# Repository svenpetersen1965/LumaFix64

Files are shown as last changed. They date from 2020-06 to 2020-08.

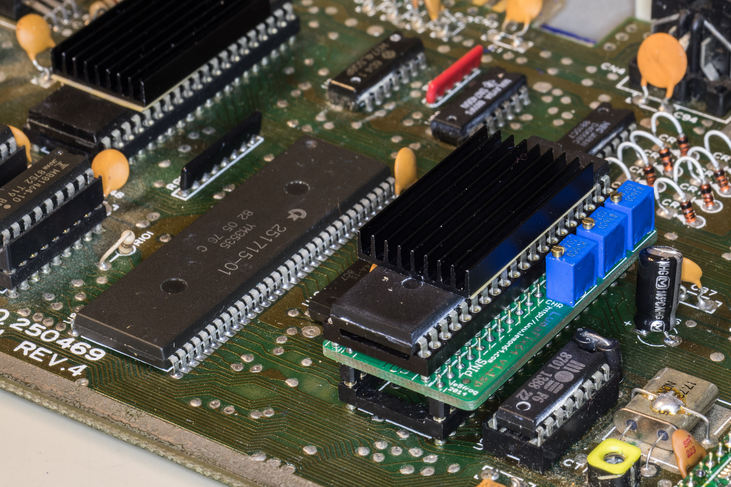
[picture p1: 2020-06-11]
v1.2/Bilder/416_LumaFix64_on_ASSY250469.JPG

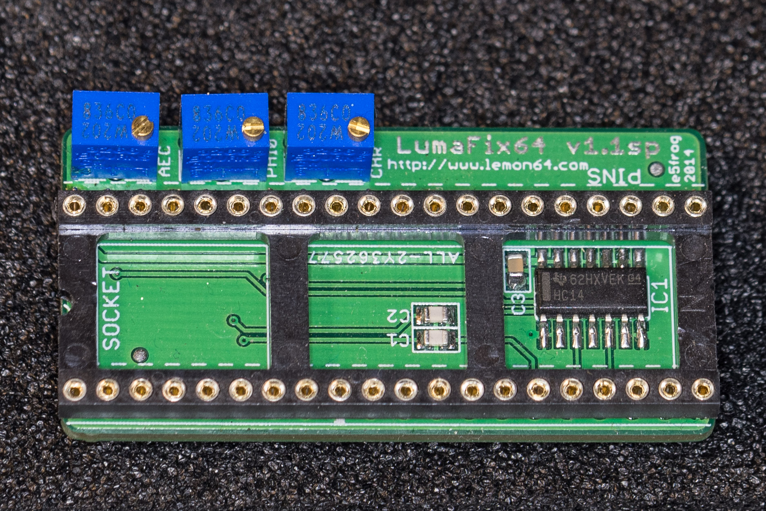
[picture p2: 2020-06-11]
v1.2/Bilder/0407_LumaFix64.JPG

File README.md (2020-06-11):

# LumaFix64
The LumaFix64 is not my design. It is based on <a href="https://www.lemon64.com/forum/viewtopic.php?t=40570&start=375">e5frog's LumaFix64 design</a>, which was released in March 7th, 2018 in the Lemon64.com forum. The changes in my design are:
* No through hole parts
* PCB a little bit narrower
* the Chroma potentiometer (CHR) can be replaced with a fix resistor or just a solder bridge

The Chroma potentiometer is IMHO not required, because it is not desirable to reduce the chominance level before the composite video signal is generated in the RF modulator. 

The LumaFix64 requires the precision round pin strips, because those are narrow enough not to break the socket of VIC-II chip. Since these pin strips are fragile, the LumaFix64 has to be handle with care.

I have received the permission of e5frog for publishing these files in this github repository (see screen shot in the "pictures" folder).

# BOM value
The calculation of the BOM values is available in the EXCEL folder. The total BOM value is 9,63€ (May 2020). This includes the Chroma pot and domestic pin strips. It is possible to save money on both, when ordering overseas.

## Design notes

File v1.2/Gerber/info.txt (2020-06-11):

      
   
       Board: LumaFix64 v1.1sp (e5frog & http://www.lemon64.com)
       Rev.:  1.2
  
       Files:
       ======
  
       All Gerber files are generated in extended gerber format (RS274X)
       *.TOP        : Film top copper
       *.BOT        :  -"- bottom copper
       *.STC        :  -"- top soldermask 
       *.STS        :  -"- bottom soldermask
       *.CRC        :  -"- cream top
       *.PLC        :  -"- silk screen top
       *.PLS        :  -"- silk screen bottom
       *.DK         : Drills plated Through (Excellon)
       *.NDK        : Drills not plated Through (Excellon)
       *.OUT        : Board outline

       Board Size:
       ===========
       Length     :   50.75 mm
       Width      :   25.94 mm
       Thickness  :   1.6 mm
       Material   :   FR 4
       Copper     :   35 um
       Surface    :   HASL
       
       Remarks:
       ========
       Drills not plated Through do not exsist on this board.
       drills >= 0.35mm
       width >= 8mil
       distance >= 6mil

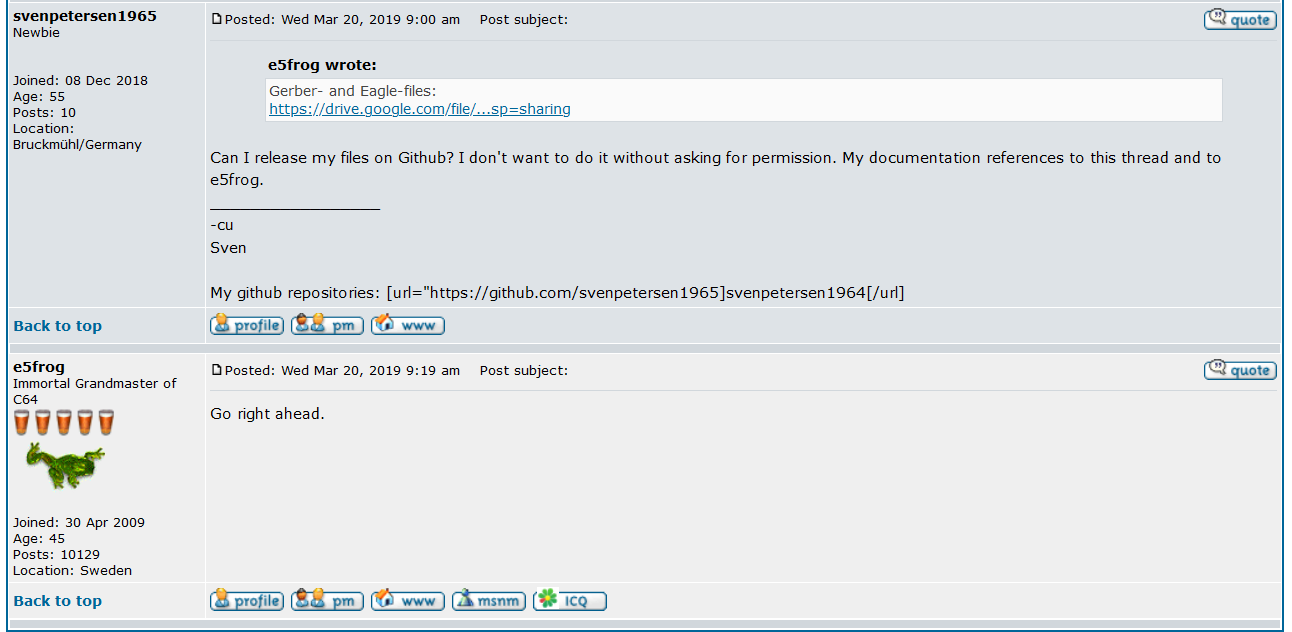
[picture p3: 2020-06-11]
v1.2/Bilder/e5frog_permission_20190320.png

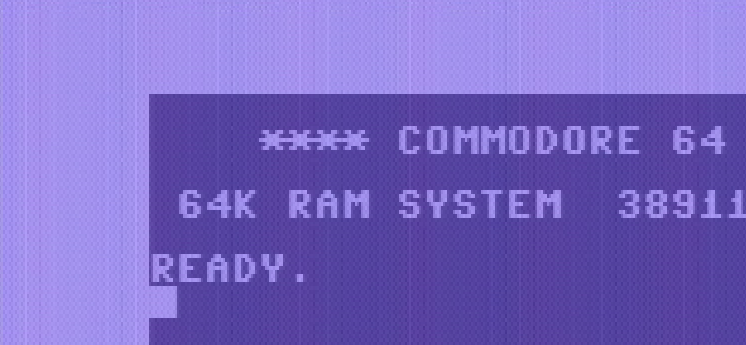
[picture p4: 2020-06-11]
v1.2/Bilder/C64_Bild_ohne_Lumafix.png

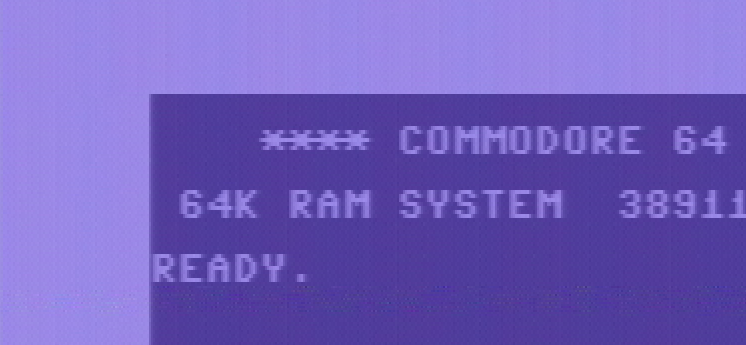
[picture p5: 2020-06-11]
v1.2/Bilder/C64_Bild_mit_Lumafix.png

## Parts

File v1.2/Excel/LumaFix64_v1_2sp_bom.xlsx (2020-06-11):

LumaFix64 Rev. 1.2sp
Partlist Rev. 1.20
Pos. | Each | Value | Footprint | Names | Anmerkung
1 | 1 | 110-2-01-01.2sp | 2 Layers | PCB Rev. 1.2sp | 2 Layers, Cu 35µ, HASL, 50.75mm 25.94mm, 1.6mm FR4
2 | 1 | DIP-40 | GS40P | SOCKET | Dual In Line Socket, Reichelt: GS40P
3 | 1 | 10120540 | BKL_10120540_2X20 | PINS | Precision pin header, bkl-electronic.de Art.-Nr. 10120540, Reichelt BKL 10120540
4 | 1 | 100n | 0805 | C3 | SMD capacitor
5 | 1 | 2k | POT_B64W | CHR | optional, only if chroma adjustment is desired. Bournes 3266W-1-202, Reichelt: BOU 3266W-1-202
6 | 2 | 2k | POT_B64W | AEC, PHI0 | Bournes 3266W-1-202, Reichelt: BOU 3266W-1-202
7 | 2 | 47p | 0805 | C1, C2 | SMD capacitor
8 | 1 | 74HCT14D | SO14 | IC1 | Hex schmitt trigger inverter, e.g. NXP, Reichelt 74HCT 14D NXP
9 | 1 | n/a | 0805 | R1 | not assembled

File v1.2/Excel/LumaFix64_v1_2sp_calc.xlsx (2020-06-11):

LumaFix64 Rev. 1.2sp
Kalkulation
Pos. | Each | Value | Footprint | €/each | Sum
1 | 1 | 110-2-01-01.2sp | 2 Layers | 1.00 € | 1.00 €
2 | 1 | DIP-40 | GS40P | 0.62 € | 0.62 €
3 | 1 | 10120540 | BKL_10120540_2X20 | 1.99 € | 1.99 €
4 | 1 | 100n | 0805 | 0.05 € | 0.05 €
5 | 1 | 2k | POT_B64W | 1.85 € | 1.85 €
6 | 2 | 2k | POT_B64W | 1.85 € | 3.70 €
7 | 2 | 47p | 0805 | 0.10 € | 0.20 €
8 | 1 | 74HCT14D | SO14 | 0.22 € | 0.22 €
9 | 1 | n/a | 0805 | 0.00 € | 0.00 €
10 |  |  |  | Total | 9.63 €

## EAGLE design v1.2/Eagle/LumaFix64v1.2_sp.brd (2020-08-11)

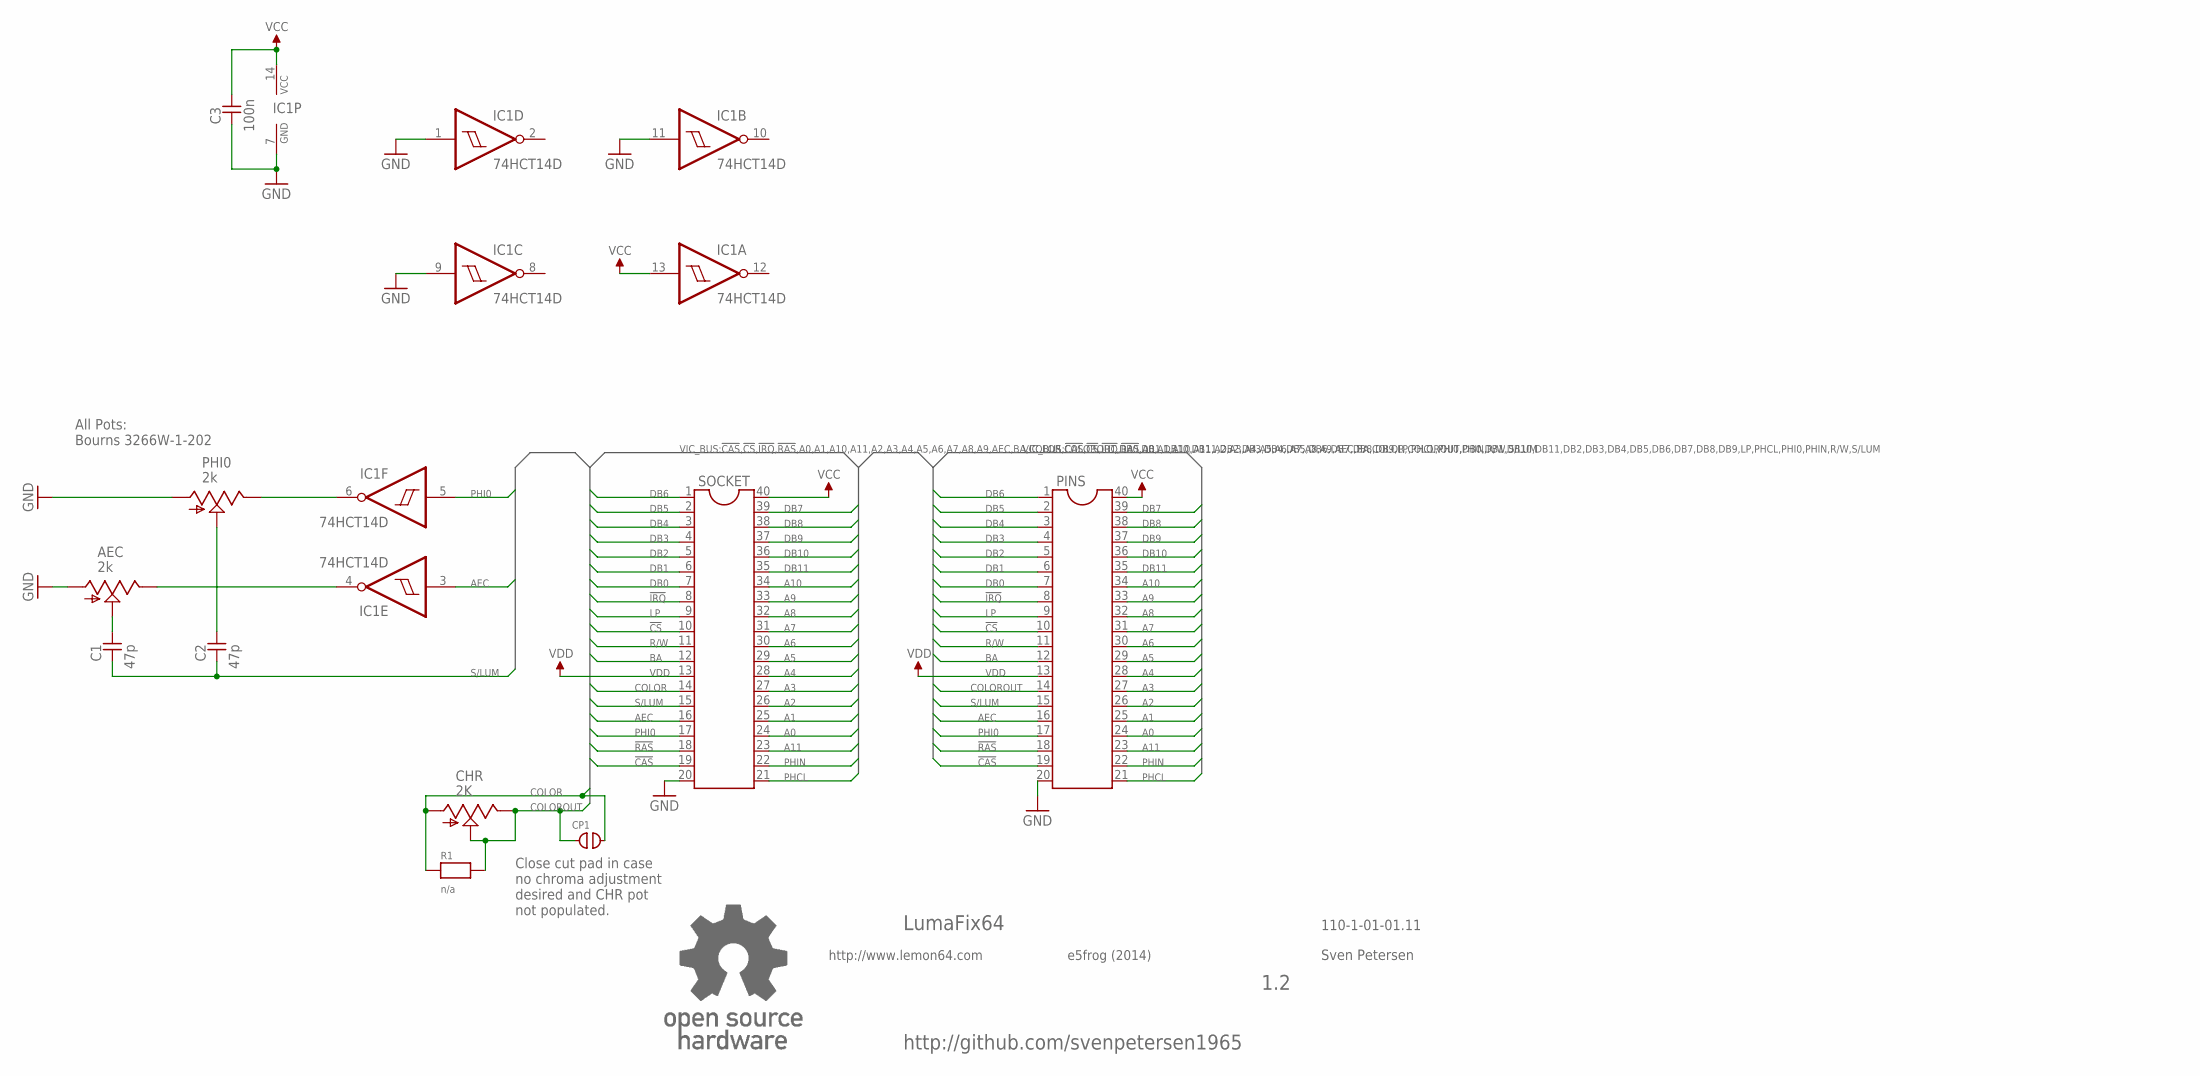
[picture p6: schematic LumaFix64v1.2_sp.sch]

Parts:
AEC: 2k; POT_B64W
C1, C2: 47p; 0805
C3: 100n; 0805
CHR: 2K; POT_B64W
CP1: OPEN; CP_OP
IC1: 74HCT14D; SO14
PHI0: 2k; POT_B64W
PINS: IC-PACKAGE_DIL40_10120540; BLK_10120540_2X20
R1: n/a; 0805
SOCKET: IC-PACKAGE_DIL40GS40P; GS40P
U$13: OPEN_SOURCE_HW; OPENHW

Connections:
!CAS: PINS.19, SOCKET.19
!CS: PINS.10, SOCKET.10
!IRQ: PINS.8, SOCKET.8
!RAS: PINS.18, SOCKET.18
A0: PINS.24, SOCKET.24
A1: PINS.25, SOCKET.25
A2: PINS.26, SOCKET.26
A3: PINS.27, SOCKET.27
A4: PINS.28, SOCKET.28
A5: PINS.29, SOCKET.29
A6: PINS.30, SOCKET.30
A7: PINS.31, SOCKET.31
A8: PINS.32, SOCKET.32
A9: PINS.33, SOCKET.33
A10: PINS.34, SOCKET.34
A11: PINS.23, SOCKET.23
AEC: IC1.3 (I), PINS.16, SOCKET.16
BA: PINS.12, SOCKET.12
COLOR: CHR.A, CP1.2, R1.1, SOCKET.14
COLOROUT: CHR.E, CHR.S, CP1.1, PINS.14, R1.2
DB0: PINS.7, SOCKET.7
DB1: PINS.6, SOCKET.6
DB2: PINS.5, SOCKET.5
DB3: PINS.4, SOCKET.4
DB4: PINS.3, SOCKET.3
DB5: PINS.2, SOCKET.2
DB6: PINS.1, SOCKET.1
DB7: PINS.39, SOCKET.39
DB8: PINS.38, SOCKET.38
DB9: PINS.37, SOCKET.37
DB10: PINS.36, SOCKET.36
DB11: PINS.35, SOCKET.35
GND: AEC.A, C3.1, IC1.1 (I), IC1.7 (GND), IC1.9 (I), IC1.11 (I), PHI0.A, PINS.20, SOCKET.20
LP: PINS.9, SOCKET.9
unnamed: AEC.S, C1.2
unnamed: C2.2, PHI0.S
unnamed: AEC.E, IC1.4 (O)
unnamed: IC1.6 (O), PHI0.E
PHCL: PINS.21, SOCKET.21
PHI0: IC1.5 (I), PINS.17, SOCKET.17
PHIN: PINS.22, SOCKET.22
R/W: PINS.11, SOCKET.11
S/LUM: C1.1, C2.1, PINS.15, SOCKET.15
VCC: C3.2, IC1.13 (I), IC1.14 (VCC), PINS.40, SOCKET.40
VDD: PINS.13, SOCKET.13

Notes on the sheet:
LumaFix64
http://www.lemon64.com
e5frog (2014)
1.2
110-1-01-01.11
Sven Petersen
All Pots: Bourns 3266W-1-202
Close cut pad in case no chroma adjustment desired and CHR pot not populated.
http://github.com/svenpetersen1965

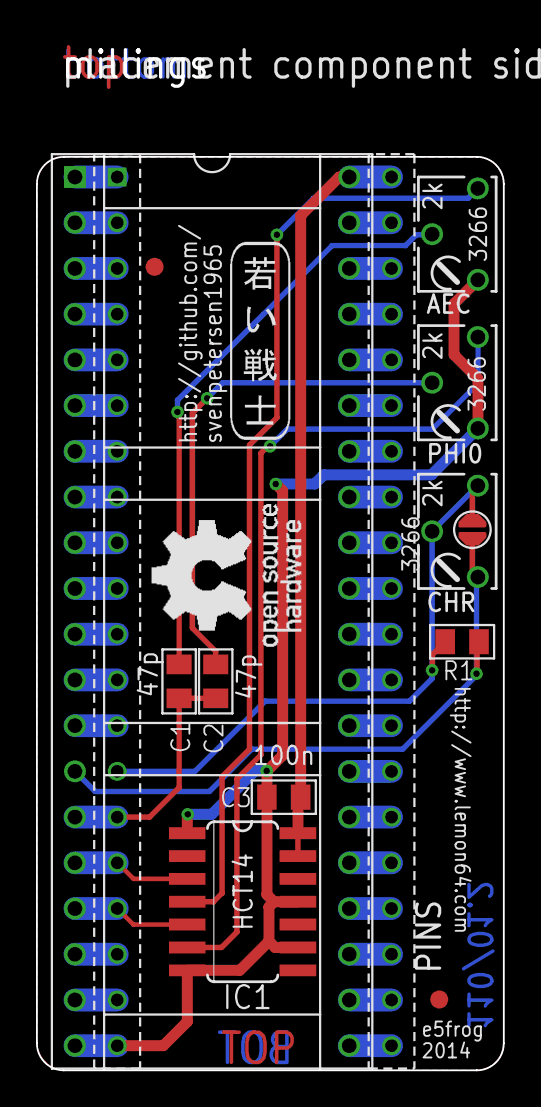
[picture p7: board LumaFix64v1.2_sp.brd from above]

Board: 2 copper layers, 25.9 x 50.8 mm, 17 parts (0 on the bottom side), 45 nets.

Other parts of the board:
U$7: 2LAYER
U$9: PCB-TITLE/
U$10, U$11: SMD_REF_R1MM
U$12: SVEN_TAG

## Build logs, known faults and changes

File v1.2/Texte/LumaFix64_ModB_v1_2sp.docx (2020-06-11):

LumaFix64 Rev. 1.2sp

Module Description

# 1. Preface

It is a known fact, that some digitals signals are interfering with the video output signals inside the VIC-II chip of the Commodore C64. This results in a typical vertical strip pattern in the monitor output of the C64. The main culprits are AEC and PHI0 (VIC-II pin 16 and 17).

This topic was discussed in the lemon64.com forum in December 2011 (https://www.lemon64.com/forum/viewtopic.php?t=40570&start=0), where the attempt to cancel out these interferences was mentioned, that was released by the user ikary_01 in forum64.de in October 2010, called „C64-Streifenfix“ (https://www.forum64.de/index.php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 (https://www.forum64.de/index.php?s=b329abcb4ddda3e4efab6bcffade57ad2a5b7f33) & https://sd2snes.de/~ikari/pics/ ).

This design is based on the eagle files LumaFix64v1.0_B64W, that e5frog released in the lemon64.com forum March 7th, 2018. (https://www.lemon64.com/forum/viewtopic.php?t=40570&start=375)

# 2. Functionality

The signals AEC and PHI0 are inverted, then attenuated by potentiometers (AEC & PHI0) and coupled into the S/LUM signal (VIC-II pin 15) via a small (47p) capacity). The potentiometers can be adjusted to minimize the interferences of the signals mentioned above.

Further on, the chrominance signal of the VIC-II chip has an amplitude, which is too high for most modern TVs, which results in a poor color quality. Many C64 video cables solve this issue by inserting a 330Ω resistor into the chrominance output signal. The LumaFix64 solves this issue with a pot (CHR) inserted in the signal. This pot can stay not populated and the cut pad CP1 can be closed instead.

# 3. Revision History

## v1.0 B64W → v1.1sp

- The issue of the original eagle files with Eagle 9 was fixed
- The schematic was restructured
- The THT ICs and capacitors were left out
- The footprints of the socket, pin headers and pots were changed
- The inverter IC 74HCT14 has a 100n buffer cap
- The cut-pad CP1for bridging the CHR pot was added, a 330Ω resistor (0603) can be placed on this cut-pad for having a fix resistor in the chrominance output.
- The width of the board was reduced to 25.94mm
- The layout is new

## v1.1sp → v1.2sp

- PCB Revision
- R1 is new to replace the CHR pot if not required

LumaFix64_ModB_v1_2sp.docx 03.04.2020 14:15 Erstellt von Sven Petersen Seite 2 von 2 Dok.-Nr.: 000-8-00-00

LumaFix64_ModB_v1_2sp.docx 03.04.2020 14:15 Drafted by Sven Petersen Page 1 of 1 Doc.-No.: 110-6-01-01.2sp

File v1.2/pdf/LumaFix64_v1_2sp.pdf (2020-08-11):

LumaFix64_ModB_v1_2sp.docx | | 03.04.2020 14:15
Drafted by Sven Petersen | Page 1 of 1 | Doc.-No.: 110-6-01-01.2sp

### LumaFix64 Rev. 1.2sp

### Module Description

## 1. Preface

It is a known fact, that some digitals signals are interfering with the video output signals inside the VIC-II chip of the Commodore C64. This results in a typical vertical strip pattern in the monitor output of the C64. The main culprits are AEC and PHI0 (VIC-II pin 16 and 17).

This topic was discussed in the lemon64.com forum in December 2011 (https://www.lemon64.com/forum/viewtopic.php?t=40570&start=0), where the attempt to cancel out these interferences was mentioned, that was released by the user ikary_01 in forum64.de in October 2010, called „C64-Streifenfix“ (https://www.forum64.de/index.php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 (https://www.forum64.de/index.php?s=b329abcb4ddda3e4efab6bcffade57ad2a5b7f33) & https://sd2snes.de/~ikari/pics/ ).

This design is based on the eagle files LumaFix64v1.0_B64W, that e5frog released in the lemon64.com forum March 7th, 2018. (https://www.lemon64.com/forum/viewtopic.php?t=40570&start=375)

## 2. Functionality

The signals AEC and PHI0 are inverted, then attenuated by potentiometers (AEC & PHI0) and coupled into the S/LUM signal (VIC-II pin 15) via a small (47p) capacity). The potentiometers can be adjusted to minimize the interferences of the signals mentioned above.

Further on, the chrominance signal of the VIC-II chip has an amplitude, which is too high for most modern TVs, which results in a poor color quality. Many C64 video cables solve this
issue by inserting a 330Ω resistor into the chrominance output signal. The LumaFix64 solves
this issue with a pot (CHR) inserted in the signal. This pot can stay not populated and the cut pad CP1 can be closed instead.

## 3. Revision History

### v1.0 B64W → v1.1sp

- The issue of the original eagle files with Eagle 9 was fixed
- The schematic was restructured
- The THT ICs and capacitors were left out
- The footprints of the socket, pin headers and pots were changed
- The inverter IC 74HCT14 has a 100n buffer cap
- The cut-pad CP1for bridging the CHR pot was added, a 330Ω resistor (0603) can be placed on this cut-pad for having a fix resistor in the chrominance output.
- The width of the board was reduced to 25.94mm
- The layout is new

### v1.1sp → v1.2sp

- PCB Revision
- R1 is new to replace the CHR pot if not required

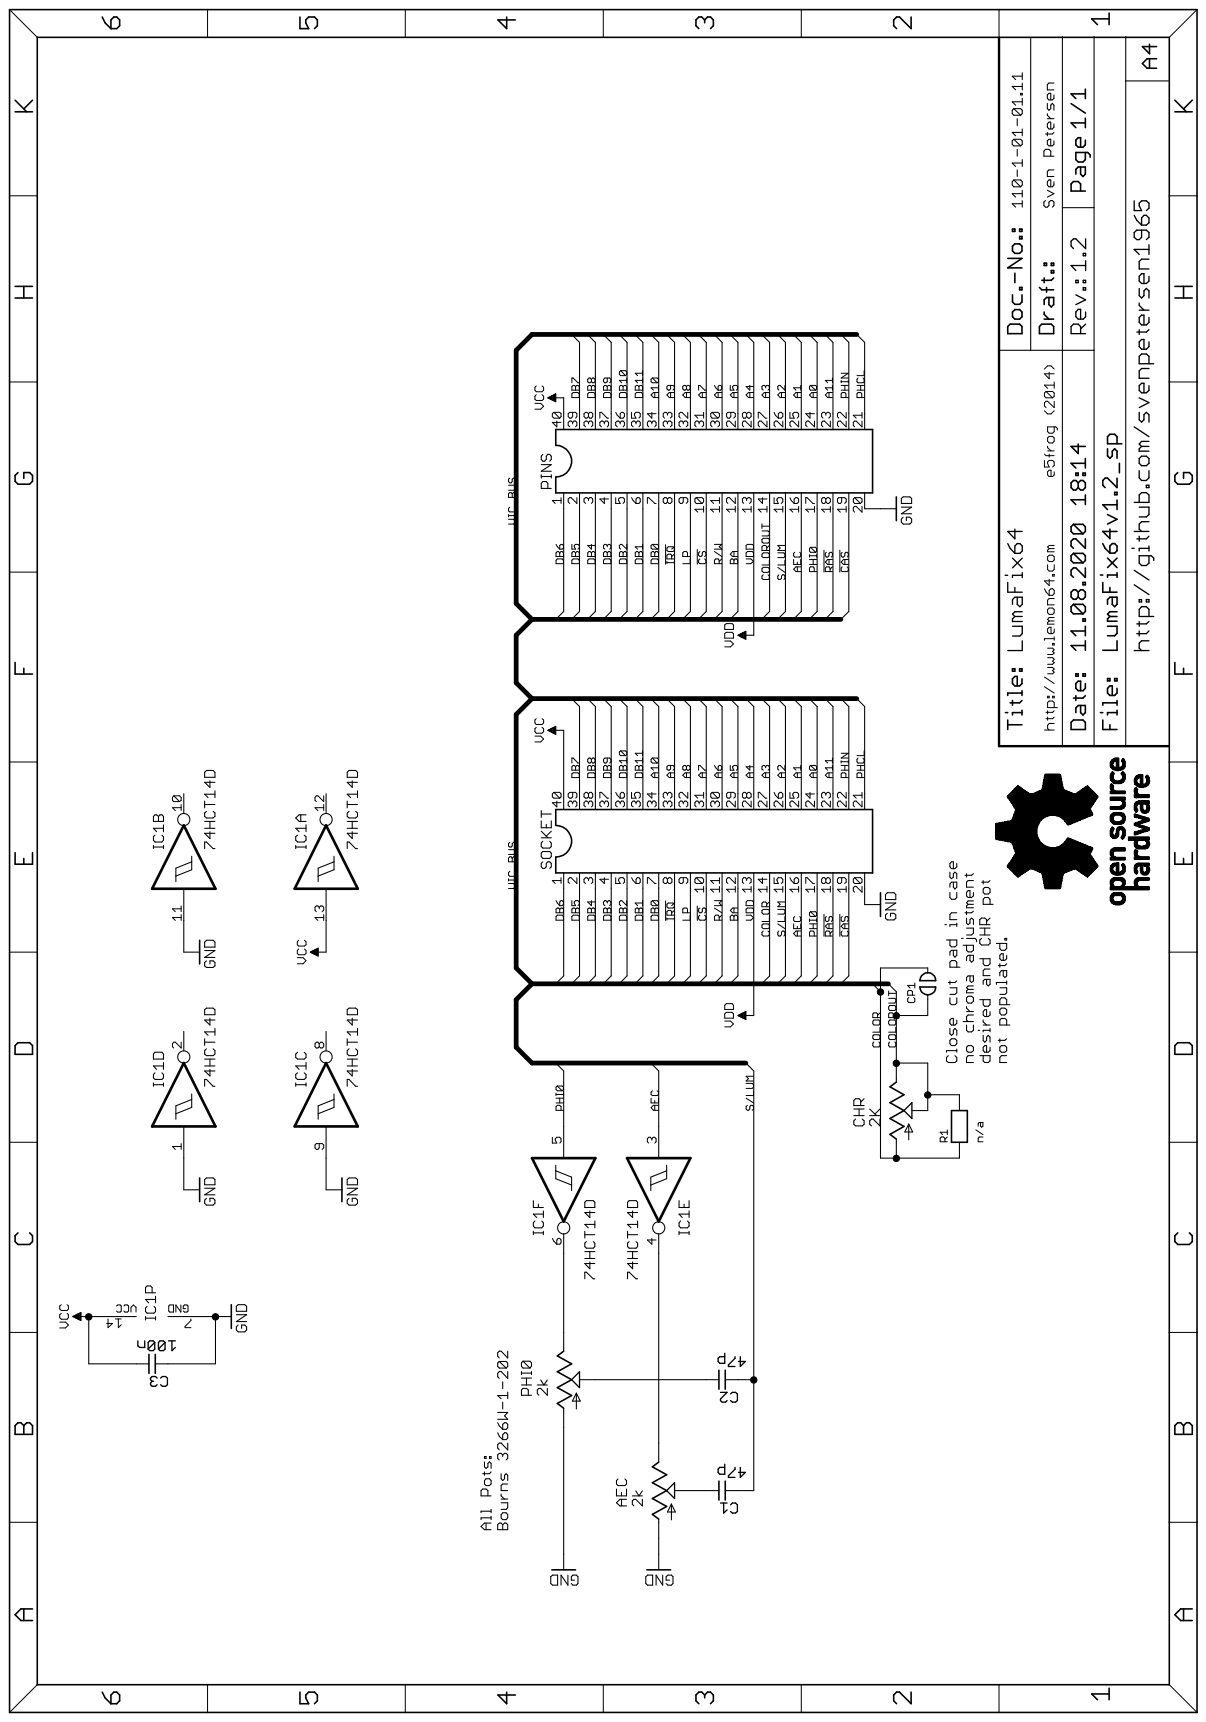
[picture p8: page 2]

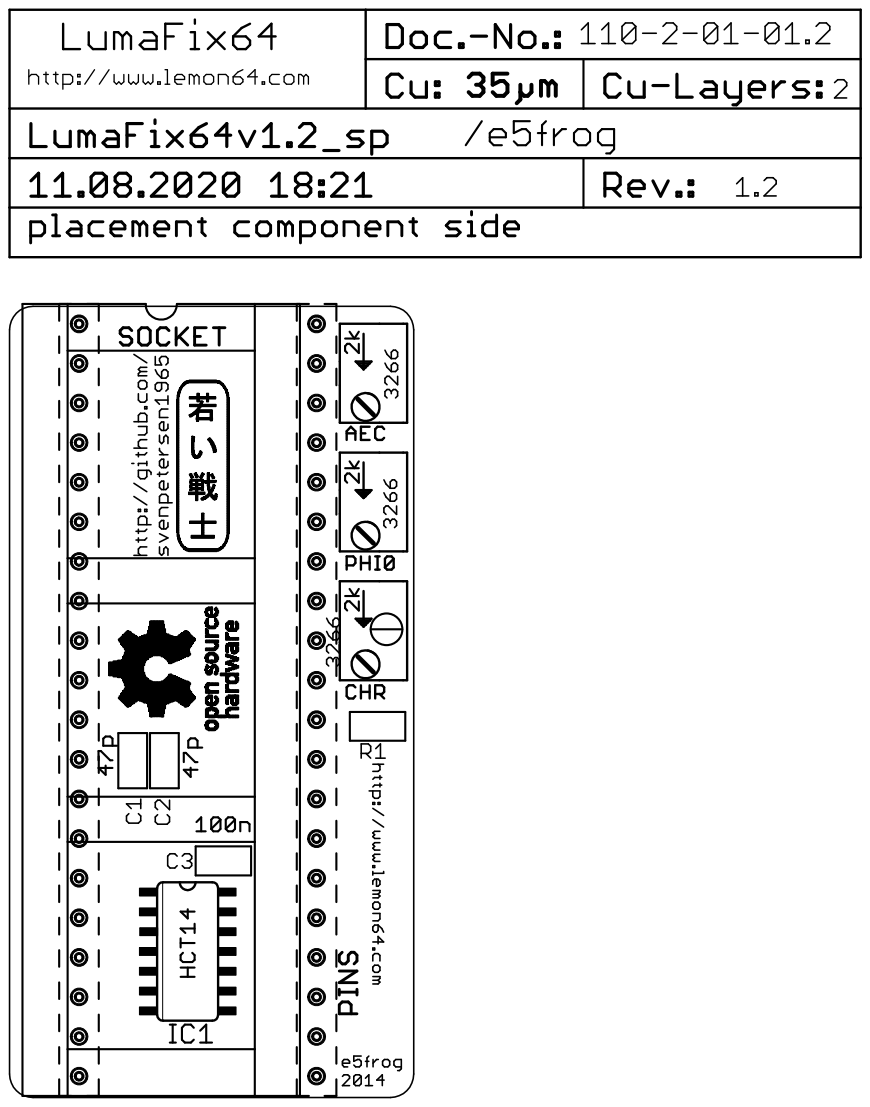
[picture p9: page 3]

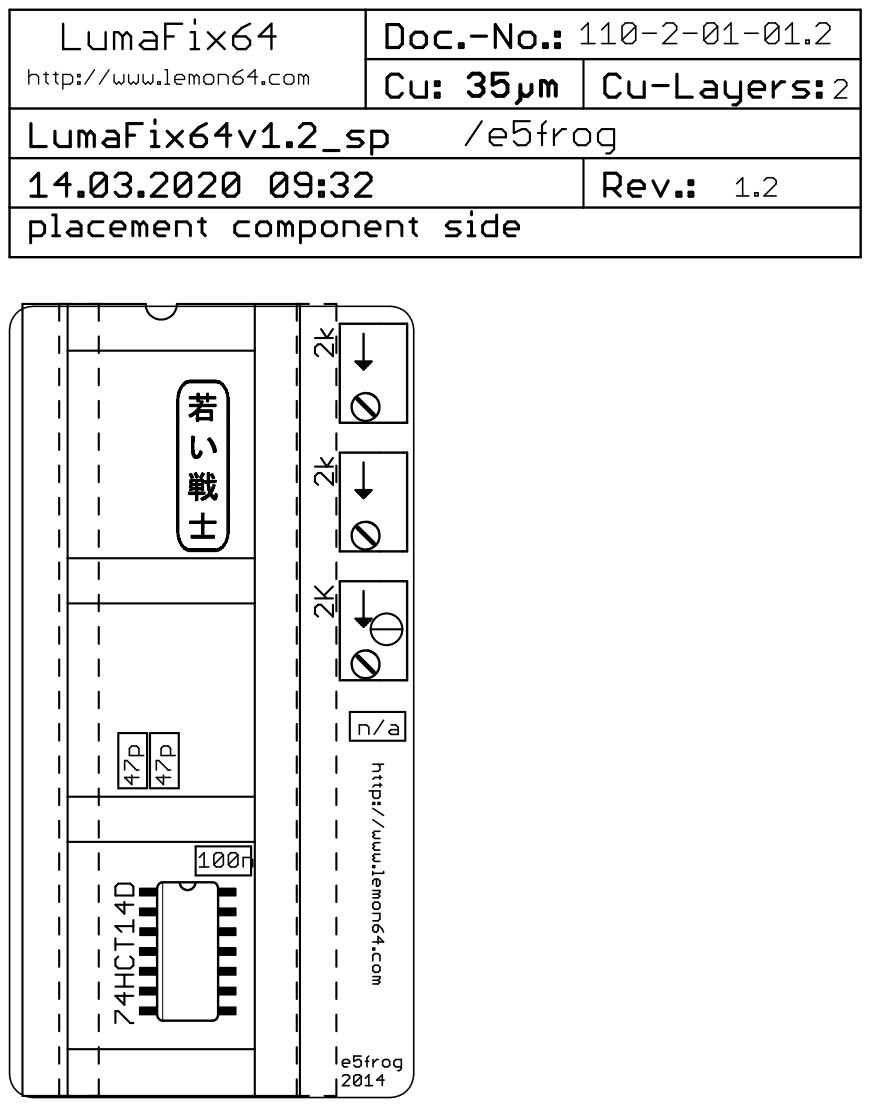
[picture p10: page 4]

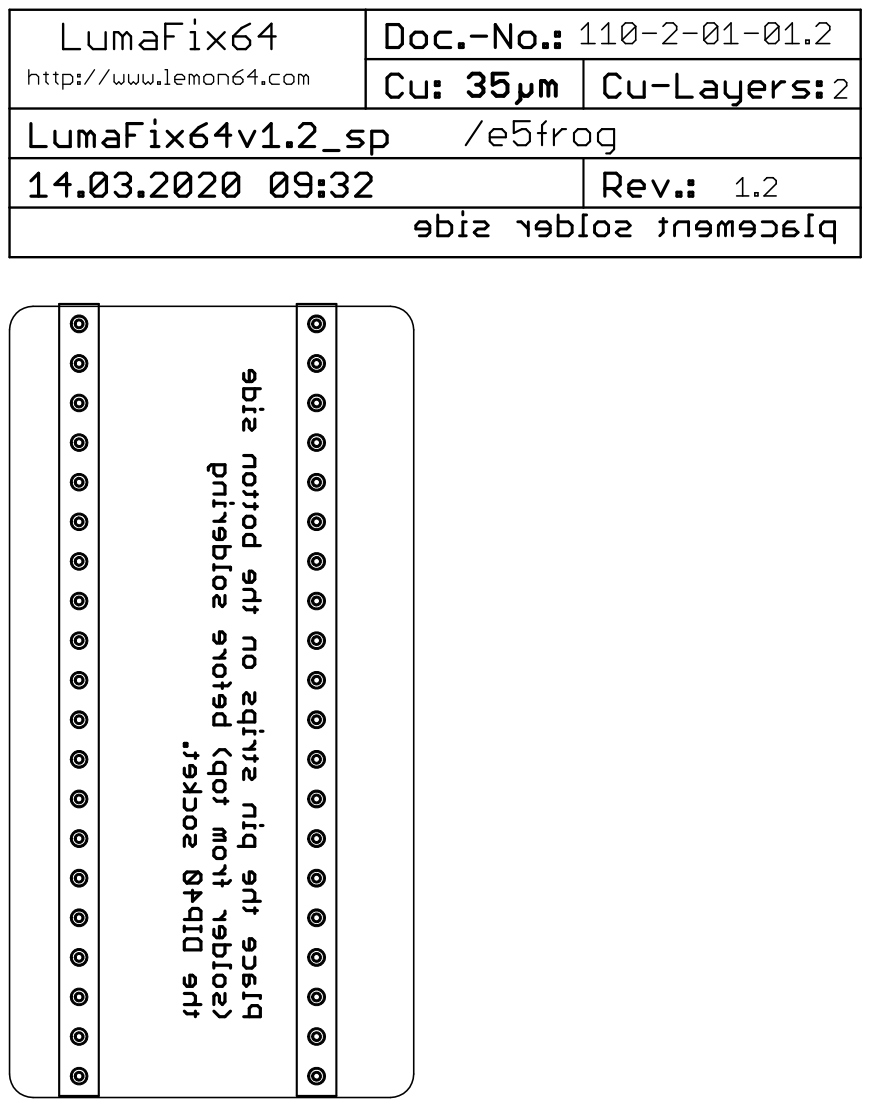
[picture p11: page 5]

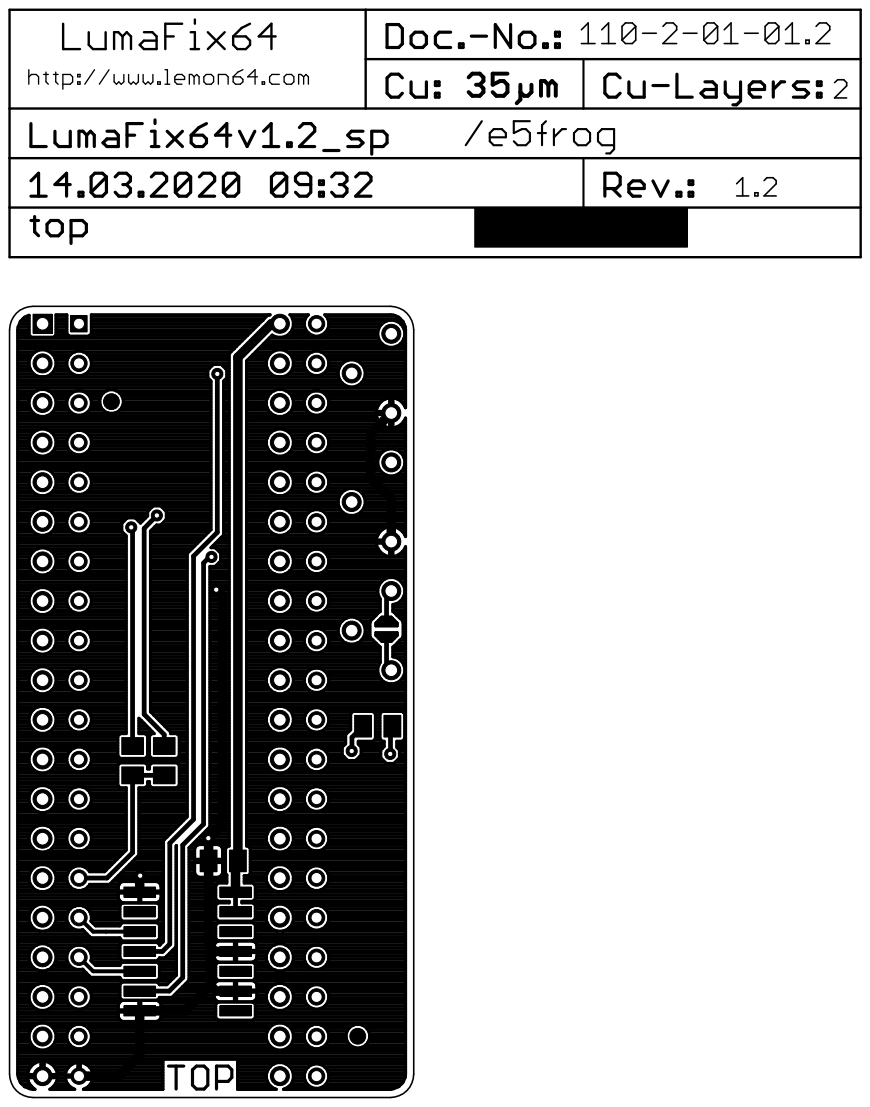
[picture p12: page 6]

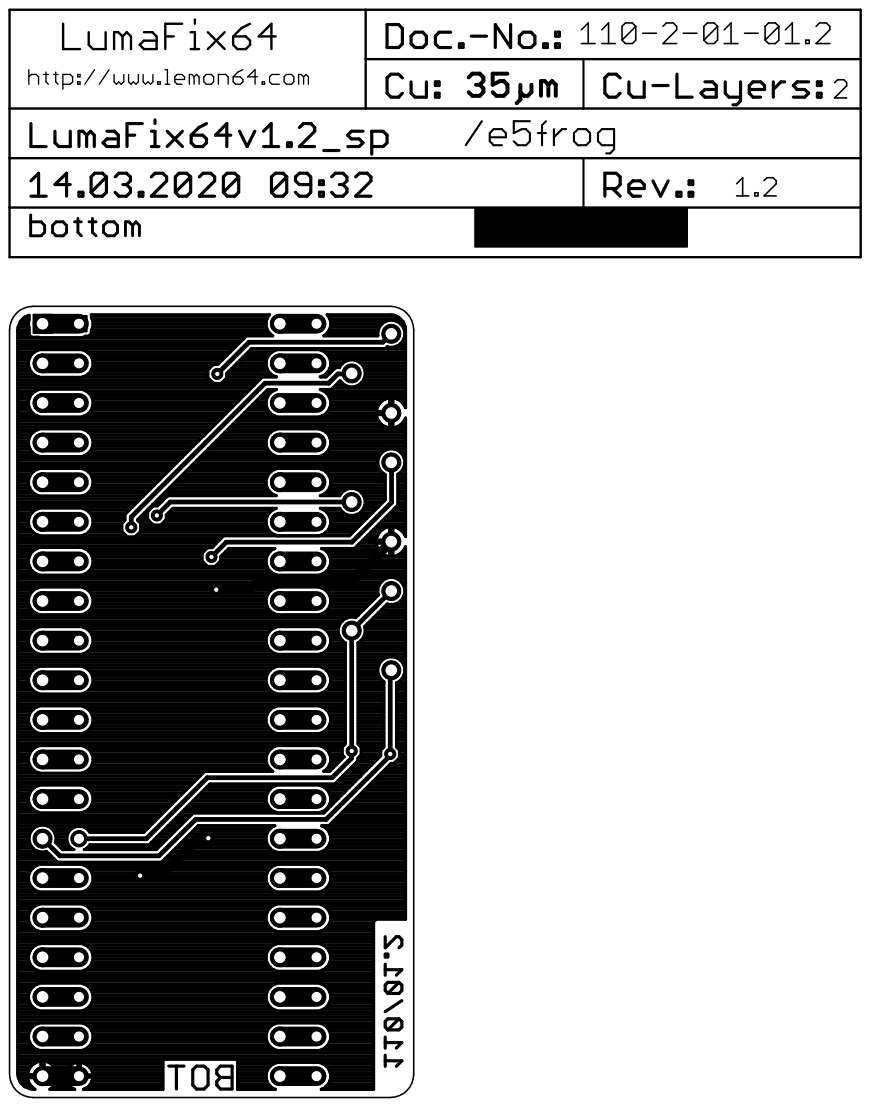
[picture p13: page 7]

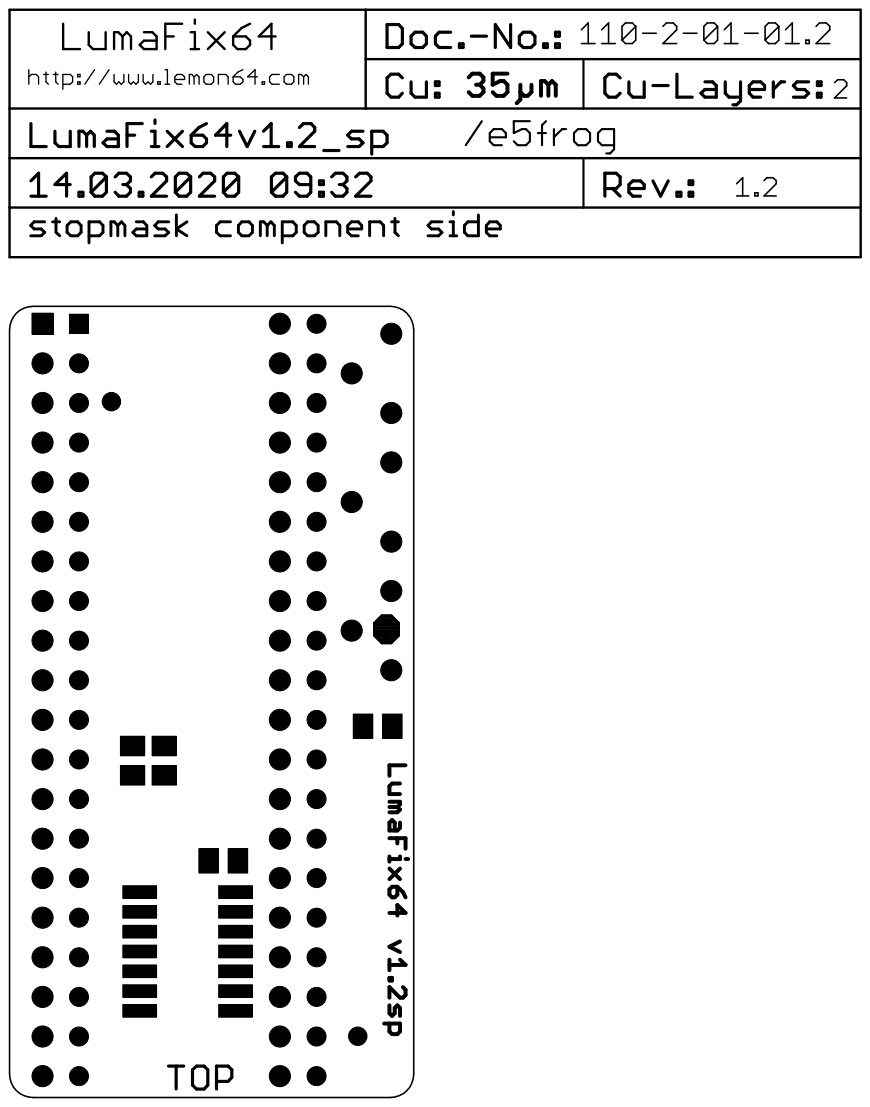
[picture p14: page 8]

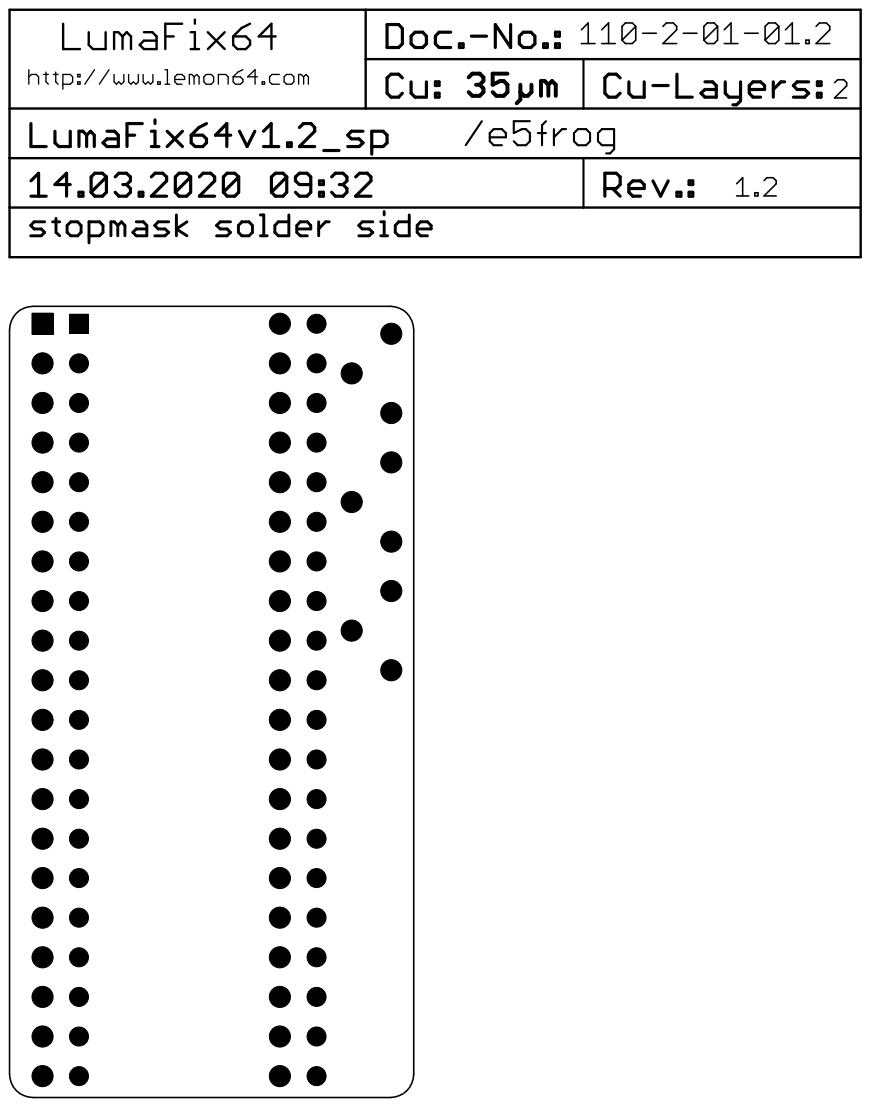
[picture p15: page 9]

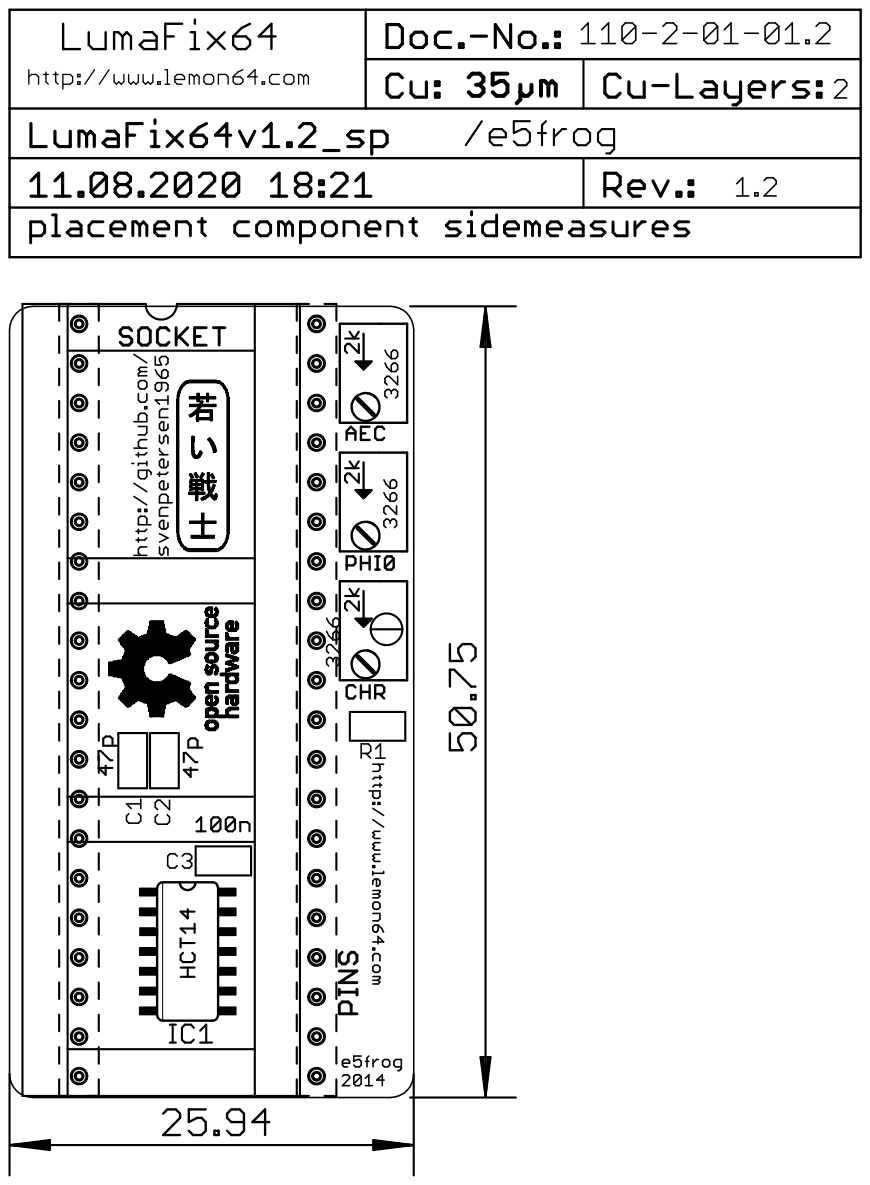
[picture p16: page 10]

Pos. Each Value Footprint Names Anmerkung

1 1 110-2-01-01.2sp 2 Layers PCB Rev. 1.2sp 2 Layers, Cu 35µ, HASL, 50.75mm 25.94mm, 1.6mm FR4

2 1 DIP-40 GS40P SOCKET Dual In Line Socket, Reichelt: GS40P

3 1 10120540 BKL_10120540_2X2

0

PINS Precision pin header, bkl-electronic.de Art.-Nr. 10120540, Reichelt BKL

10120540

4 1 100n 0805 C3 SMD capacitor

5 1 2k POT_B64W CHR optional, only if chroma adjustment is desired. Bournes 3266W-1-202,

Reichelt: BOU 3266W-1-202

6 2 2k POT_B64W AEC, PHI0 Bournes 3266W-1-202, Reichelt: BOU 3266W-1-202

7 2 47p 0805 C1, C2 SMD capacitor

8 1 74HCT14D SO14 IC1 Hex schmitt trigger inverter, e.g. NXP, Reichelt 74HCT 14D NXP

## LumaFix64 Rev. 1.2sp

## Partlist Rev. 1.20

LumaFix64_v1_2sp_bom.xlsx

Erstellt von Sven Petersen Seite 1 von 1

03.04.2020 14:17
Dok.Nr.: 110-5-01-01.20

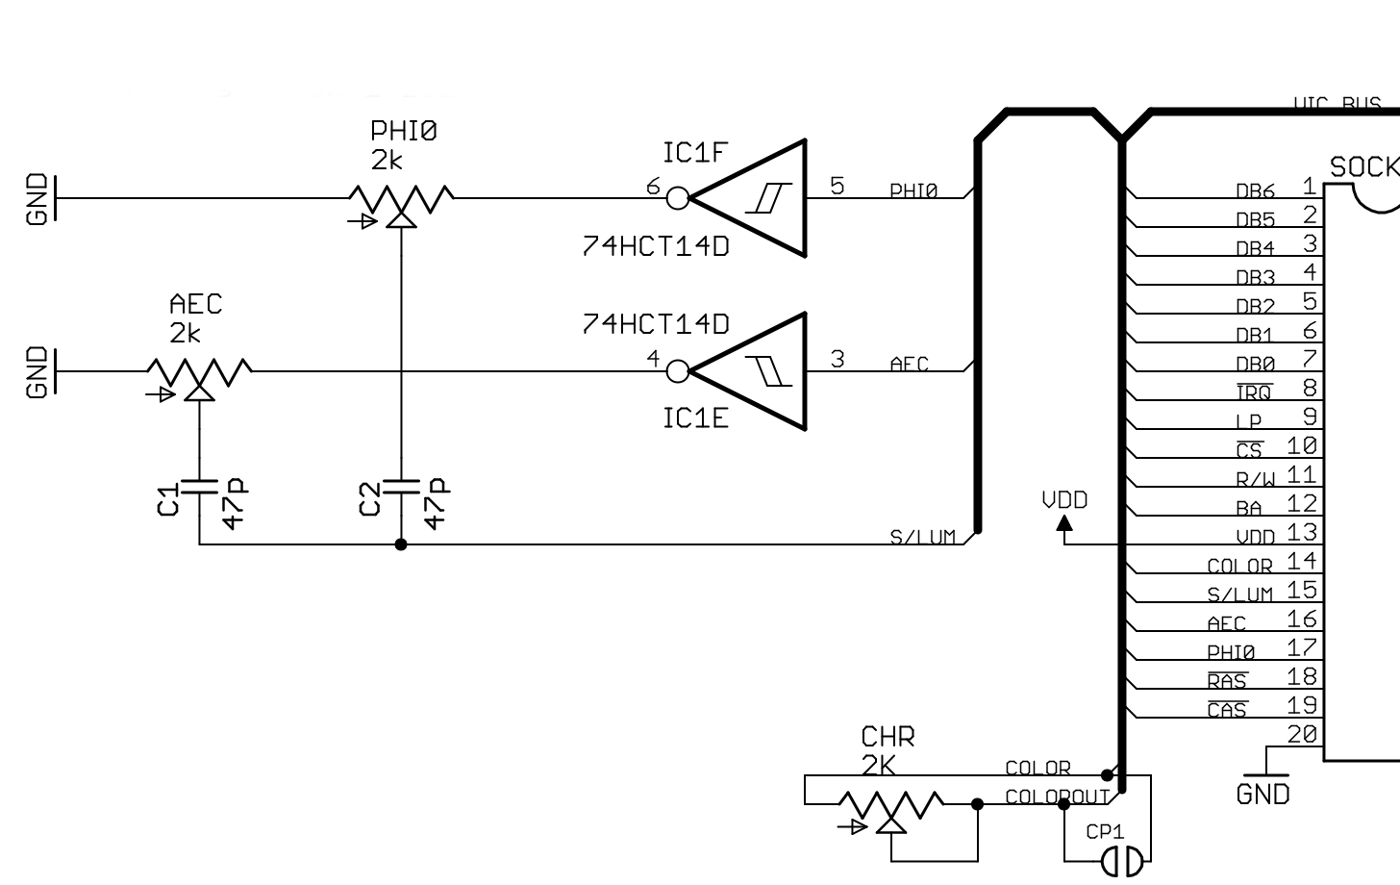
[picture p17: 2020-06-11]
v1.2/Bilder/LumaFix64_v1.1_sch.png
